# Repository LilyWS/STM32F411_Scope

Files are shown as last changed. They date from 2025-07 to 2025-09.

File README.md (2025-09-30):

Pretty much everything happens in main.c 

Signal conditioning phase consists of a voltage divider, diodes to clamp power to the rails, and an op-amp buffer to ensure proper current to the adc. 

I am interested in adding support for negative voltages through a dc bias to signals. I have yet to test the oscilliscopes capabilities thoroughly although it appears it's unable to accurately determine frequency past 150kHz or so.

The rightmost bread board is just a 555 for testing purposes. The middle one contains the signal condition phase and button inputs (which are still rather bouncy). 
The left most connects the STM32 to the screen, an ILI9488. 
The screen is rather slow to refresh, definetly not the best choice for this project. I regret powering the screen from the F411 as the power rails are rather inconsistent now (hence the need for reading Vrefint to infer true power voltage). I am interested in powering them separately in the future. 

The KiCad project folder for the PCB is the folder name Oscilliscope.







IOC
Clock

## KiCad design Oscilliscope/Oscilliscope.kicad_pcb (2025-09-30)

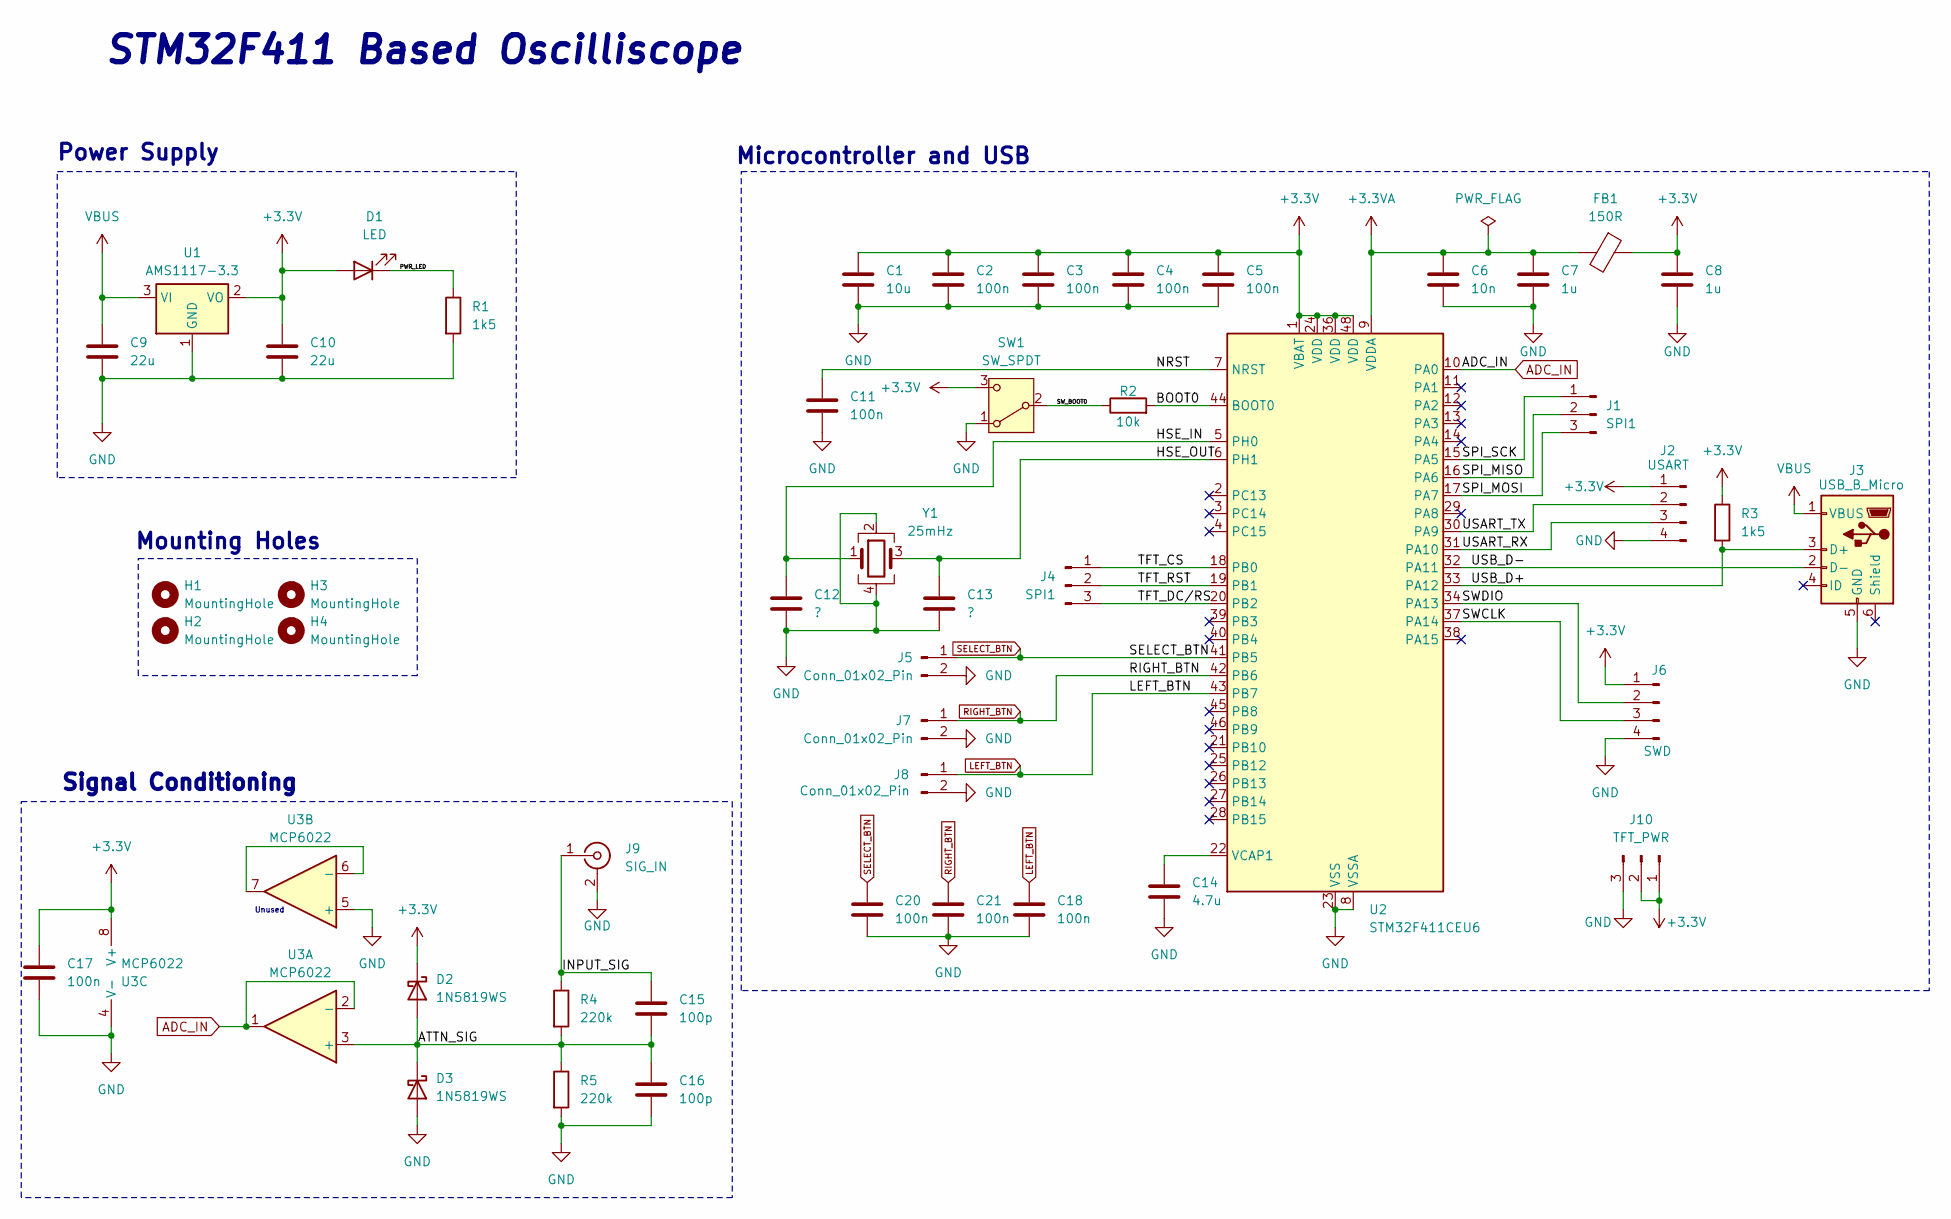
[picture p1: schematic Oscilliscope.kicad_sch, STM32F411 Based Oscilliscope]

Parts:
C1: 10u; C_0805_2012Metric
C2, C3, C4, C5, C11, C17, C18, C20, C21: 100n; C_0402_1005Metric
C6: 10n; C_0402_1005Metric
C7, C8: 1u; C_0402_1005Metric
C9, C10: 22u; C_0805_2012Metric
C12, C13: ?; C_0402_1005Metric
C14: 4.7u; C_0805_2012Metric
C15, C16: 100p; C_0402_1005Metric
D1: LED; LED_0603_1608Metric
D2, D3: 1N5819WS; D_SOD-323
FB1: 150R; L_0603_1608Metric
H1, H2, H3, H4: MountingHole; MountingHole_2.2mm_M2
J1, J4: SPI1; PinHeader_1x03_P2.54mm_Vertical
J2: USART; PinHeader_1x04_P2.54mm_Vertical
J3: USB_B_Micro; USB_Micro-B_Wuerth_629105150521
J5, J7, J8: Conn_01x02_Pin; PinHeader_1x02_P2.54mm_Vertical
J6: SWD; PinHeader_1x04_P2.54mm_Vertical
J9: SIG_IN; PinHeader_1x02_P2.54mm_Vertical
J10: TFT_PWR; PinHeader_1x03_P2.54mm_Vertical
R1, R3: 1k5; R_0402_1005Metric
R2: 10k; R_0402_1005Metric
R4, R5: 220k; R_0402_1005Metric
SW1: SW_SPDT; SW_SPDT_PCM12
U1: AMS1117-3.3; SOT-223-3_TabPin2
U2: STM32F411CEU6; QFN-48-1EP_7x7mm_P0.5mm_EP5.6x5.6mm
U3: MCP6022; DIP-8_W7.62mm
Y1: 25mHz; Crystal_SMD_3225-4Pin_3.2x2.5mm

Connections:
+3.3V: C1.1, C2.1, C3.1, C4.1, C5.1, C8.1, C10.1, C17.1, D1.2 (A), D2.1 (K), FB1.1, J2.1, J6.1, J10.1, J10.2, R3.1, SW1.3 (C), U1.2 (VO), U2.1 (VBAT), U2.24 (VDD), U2.36 (VDD), U2.48 (VDD), U3.8 (V+); also elsewhere on the board
+3.3VA: C6.1, C7.1, FB1.2, U2.9 (VDDA)
/ATTN_SIG: C15.2, C16.1, D2.2 (A), D3.1 (K), R4.2, R5.1, U3.3 (+)
/BOOT0: R2.2, U2.44 (BOOT0)
/HSE_IN: C12.1, U2.5 (PH0), Y1.1
/HSE_OUT: C13.1, U2.6 (PH1), Y1.3
/INPUT_SIG: C15.1, J9.1 (In), R4.1
/NRST: C11.1, U2.7 (NRST)
/PWR_LED: D1.1 (K), R1.1
/SPI_MISO: J1.2, U2.16 (PA6)
/SPI_MOSI: J1.3, U2.17 (PA7)
/SPI_SCK: J1.1, U2.15 (PA5)
/SWCLK: J6.3, U2.37 (PA14)
/SWDIO: J6.2, U2.34 (PA13)
/SW_BOOT0: R2.1, SW1.2 (B); also elsewhere on the board
/TFT_CS: J4.1, U2.18 (PB0)
/TFT_DC/RS: J4.3, U2.20 (PB2)
/TFT_RST: J4.2, U2.19 (PB1)
/USART_RX: J2.3, U2.31 (PA10)
/USART_TX: J2.2, U2.30 (PA9)
/USB_D+: J3.3 (D+), R3.2, U2.33 (PA12)
/USB_D-: J3.2 (D-), U2.32 (PA11)
ADC_IN: U2.10 (PA0), U3.1, U3.2 (-)
GND: C1.2, C2.2, C3.2, C4.2, C5.2, C6.2, C7.2, C8.2, C9.2, C10.2, C11.2, C12.2, C13.2, C14.2, C16.2, C17.2, C18.1, C20.1, C21.1, D3.2 (A), J2.4, J3.5 (GND), J5.2, J6.4, J7.2, J8.2, J9.2 (Ext), J10.3, R1.2, R5.2, SW1.1 (A), U1.1 (GND), U2.8 (VSSA), U2.23 (VSS), U2.35 (VSS), U2.47 (VSS), U2.49 (VSS), U3.4 (V-), U3.5 (+), Y1.2, Y1.4; also elsewhere on the board
LEFT_BTN: C18.2, J8.1, U2.43 (PB7)
unnamed: C14.1, U2.22 (VCAP1)
unnamed: U3.6 (-), U3.7
RIGHT_BTN: C21.2, J7.1, U2.42 (PB6)
SELECT_BTN: C20.2, J5.1, U2.41 (PB5)
VBUS: C9.1, J3.1 (VBUS), U1.3 (VI)

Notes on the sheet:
Mounting Holes
Microcontroller and USB
Power Supply
STM32F411 Based Oscilliscope
Unused
Signal Conditioning

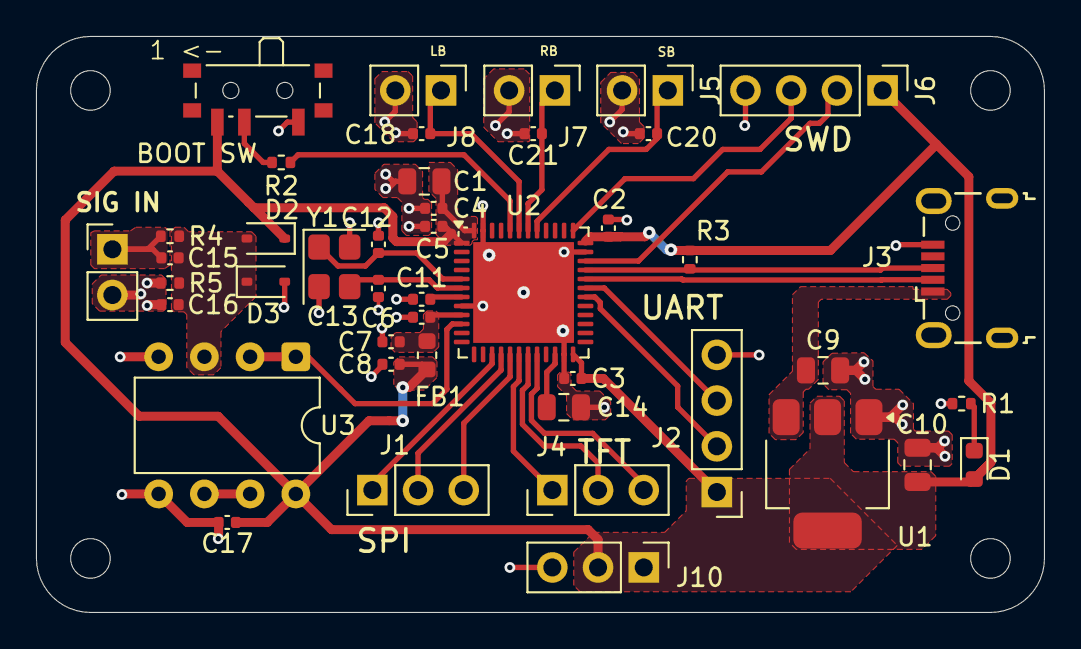
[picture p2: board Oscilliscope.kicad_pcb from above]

Board: 2 copper layers, 56.0 x 32.0 mm, 48 parts (0 on the bottom side), 30 nets.

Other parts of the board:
BOOT SW: SW_SPDT; SW_SPDT_PCM12

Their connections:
+3.3V: BOOT SW.3 (C); also elsewhere on the board
/SW_BOOT0: BOOT SW.2 (B); also elsewhere on the board
GND: BOOT SW.1 (A); also elsewhere on the board

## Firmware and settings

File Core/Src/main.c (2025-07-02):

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
/* Includes ------------------------------------------------------------------*/
#include "main.h"

/* USER CODE BEGIN Includes */
#include "ili9488.h"
#include "xpt2046.h"
#include "stdio.h"

#include "008_Open_Sans_Bold.h"
#include "009_Open_Sans_Bold.h"
#include "010_Open_Sans_Bold.h"
#include "012_Open_Sans_Bold.h"
#include "014_Open_Sans_Bold.h"
#include "016_Open_Sans_Bold.h"
#include "018_Open_Sans_Bold.h"
#include "020_Open_Sans_Bold.h"
#include "022_Open_Sans_Bold.h"
#include "024_Open_Sans_Bold.h"
#include "026_Open_Sans_Bold.h"
#include "028_Open_Sans_Bold.h"
#include "036_Open_Sans_Bold.h"
#include "048_Open_Sans_Bold.h"
#include "072_Open_Sans_Bold.h"
#include "096_Open_Sans_Bold.h"
#include "112_Open_Sans_Bold.h"
#include "128_Open_Sans_Bold.h"

#define _Open_Sans_Bold_8      &Open_Sans_Bold_8
#define _Open_Sans_Bold_9      &Open_Sans_Bold_9
#define _Open_Sans_Bold_10     &Open_Sans_Bold_10
#define _Open_Sans_Bold_11     &Open_Sans_Bold_11
#define _Open_Sans_Bold_12      &Open_Sans_Bold_12
#define _Open_Sans_Bold_14      &Open_Sans_Bold_14
#define _Open_Sans_Bold_16      &Open_Sans_Bold_16
#define _Open_Sans_Bold_18      &Open_Sans_Bold_18
#define _Open_Sans_Bold_20      &Open_Sans_Bold_20
#define _Open_Sans_Bold_22      &Open_Sans_Bold_22
#define _Open_Sans_Bold_24      &Open_Sans_Bold_24
#define _Open_Sans_Bold_26      &Open_Sans_Bold_26
#define _Open_Sans_Bold_28      &Open_Sans_Bold_28
#define _Open_Sans_Bold_36      &Open_Sans_Bold_36
#define _Open_Sans_Bold_48      &Open_Sans_Bold_48
#define _Open_Sans_Bold_72      &Open_Sans_Bold_72
#define _Open_Sans_Bold_96      &Open_Sans_Bold_96
#define _Open_Sans_Bold_112      &Open_Sans_Bold_112
#define _Open_Sans_Bold_128      &Open_Sans_Bold_128

volatile uint8_t SPI1_TX_completed_flag = 1;

char buf1[20];



#define RED2RED 0
#define GREEN2GREEN 1
#define BLUE2BLUE 2
#define BLUE2RED 3
#define GREEN2RED 4
#define RED2GREEN 5
#define BBLACK 6
//#define Aqua 7

#define BYELLOW 8


uint16_t AA[315]={315,314,313,312,311,310,309,308,307,306,305,304,303,302,301,300,299,298,297,296,
		295,294,293,292,291,290,289,288,287,286,285,284,283,282,281,280,279,278,277,276,275,274,
		273,272,271,270,269,268,267,266,265,264,263,262,261,260,259,258,257,256,255,254,253,252,
		251,250,249,248,247,246,245,244,243,242,241,240,239,238,237,236,235,234,233,232,231,230,
		229,228,227,226,225,224,223,222,221,220,219,218,217,216,215,214,213,212,211,210,209,208,
		207,206,205,204,203,202,201,200,199,198,197,196,195,194,193,192,191,190,189,188,187,186,
		185,184,183,182,181,180,179,178,177,176,175,174,173,172,171,170,169,168,167,166,165,164,
		163,162,161,160,159,158,157,156,155,154,153,152,151,150,149,148,147,146,145,144,143,142,
		141,140,139,138,137,136,135,134,133,132,131,130,129,128,127,126,125,124,123,122,121,120,
		119,118,117,116,115,114,113,112,111,110,109,108,107,106,105,104,103,102,101,100,99,98,97,
		96,95,94,93,92,91,90,89,88,87,86,85,84,83,82,81,80,79,78,77,76,75,74,73,72,71,70,69,68,67,
		66,65,64,63,62,61,60,59,58,57,56,55,54,53,52,51,50,49,48,47,46,45,44,43,42,41,40,39,38,37,
		36,35,34,33,32,31,30,29,28,27,26,25,24,23,22,21,20,19,18,17,16,15,14,13,12,11,10,9,8,7,6,5,
		4,3,2,1};

/* USER CODE END Includes */

/* USER CODE BEGIN PD */
//#define VREFINT_CAL_ADDR ((uint16_t*)0x1FFF7A2A) //compared against actual VREFINT to determine actual VDDA for ADC accuracy

/* USER CODE END PD */

ADC_HandleTypeDef hadc1;
DMA_HandleTypeDef hdma_adc1;

SPI_HandleTypeDef hspi1;
SPI_HandleTypeDef hspi2;
DMA_HandleTypeDef hdma_spi1_tx;

TIM_HandleTypeDef htim2;
TIM_HandleTypeDef htim3;

void SystemClock_Config(void);
static void MX_GPIO_Init(void);
static void MX_DMA_Init(void);
static void MX_ADC1_Init(void);
static void MX_SPI1_Init(void);
static void MX_SPI2_Init(void);
static void MX_TIM2_Init(void);
static void MX_TIM3_Init(void);
/* USER CODE BEGIN 0 */
void HAL_SPI_TxCpltCallback(SPI_HandleTypeDef *hspi)
{
	SPI1_TX_completed_flag = 1;
}


//ADC vars
#define ADC_BUF_LEN 1024//1024
#define SYSCLK_FREQ 100000000
#define CLOCKTIM_PRESC 0
volatile uint16_t adc_buf[ADC_BUF_LEN];
//test ADCVars
uint32_t adcValue = 0;
uint16_t adcCallbackTracker = 0; //track how many times buffer has filled so can call VREFINT
int triggerVDDAInfer = 0;
int triggerDisplay = 0;
char adcCharBuffer[16];

//stats to be kept track of for each buffer
uint16_t maxVoltage = 0;
uint16_t minVoltage = 4095;
uint32_t avgVoltage = 0;
double rmsVoltage = 0;
uint8_t attenuation = 2;
//triggering stuff
int triggering = 1; //if we should look for triggers
uint16_t triggerVoltage = 500; //voltage level needed to trigger
int triggersFound, triggerPoint1, triggerPoint2 = 0;
int risingTrigger = 0; //if trigger should be rising or falling
//timing stuff
uint32_t wavePeriod = 0;
uint32_t waveFrequency = 0;
uint32_t timerFrequency = 0;
uint32_t timeStep = 3; //timestep index : per div in microseconds
uint32_t timeStepOptions[11] = {35, 50, 100, 250, 500, 1000, 5000, 25000, 100000, 500000, 1000000};
//screen vars
uint8_t xDiv = 17;
uint8_t yDiv = 11;
uint8_t samplesPerDiv = 32; //should be a calculation ideally but okay to keep as constant . Found by (ADC_BUF_LEN/2)/(xDiv-1)
//manually selecting channels for VREFINT calibration, wont be needed later when switch to DMA
ADC_ChannelConfTypeDef ADC_CH_Cfg = {0};

//vars for VREFINT based ADC calibration
uint32_t vrefintReading = 0;
uint32_t inferredVDDA = 0;

//TESTING DELETE ME
uint16_t yTrack = 20;
uint16_t xTrack = 0;

//use reading from VREFINT to infer what real VDDA is
//assumes &hadc1
void inferVDDA(void){
	HAL_ADC_Stop_DMA(&hadc1);
	ADC1->CR2 &= ~(ADC_CR2_EXTEN | ADC_CR2_EXTSEL); // disable external trigger
	ADC_CH_Cfg.Channel = ADC_CHANNEL_VREFINT;        // Select The ADC Channel [i]
	ADC_CH_Cfg.Rank = 1;          // Must specify rank
	ADC_CH_Cfg.SamplingTime = ADC_SAMPLETIME_480CYCLES; // Use a long sample time
	HAL_ADC_ConfigChannel(&hadc1, &ADC_CH_Cfg); // Configure The Selected ADC Channel
    HAL_ADC_Start(&hadc1);                         // Start ADC Conversion @ Selected Channel
    HAL_ADC_PollForConversion(&hadc1, 1);         // Poll The ADC Channel With TimeOut = 1mSec

    vrefintReading = HAL_ADC_GetValue(&hadc1); // Read the result
    uint32_t vrefint_cal = *VREFINT_CAL_ADDR; // Factory calibration value
    //3300 is expected VDA in millivolts
    //dividing calibration value from factory by what was read to infer real VDDA
    inferredVDDA = (vrefint_cal*3300)/(vrefintReading);//(int)3.3f * (vrefint_cal / vrefintReading)*1000;

    HAL_ADC_Stop(&hadc1);
	ADC_CH_Cfg.Channel = ADC_CHANNEL_0;        // Select The ADC Channel
	ADC_CH_Cfg.Rank = 1;          // Must specify rank
	ADC_CH_Cfg.SamplingTime = ADC_SAMPLETIME_15CYCLES; //SET TO 15 RIGHT NOW FOR ACCURACY TAKE A LOOK AT LATER IF MORE SPEED IS NEEDED
	HAL_ADC_ConfigChannel(&hadc1, &ADC_CH_Cfg); // Configure The Selected ADC Channel
	ADC1->CR2 |= (ADC_CR2_EXTEN_0); // Rising edge
	ADC1->CR2 |= (ADC_CR2_EXTSEL_3); //Selects Timer 3 TRGO
}

//halffull ADC buffer callback
//void HAL_ADC_ConvHalfCpltCallback(ADC_HandleTypeDef* hadc) {
//	if (hadc->Instance == ADC1) {
//		// adc_buf[0] to adc_buf[half ADC_BUF_LEN-1] are ready to process
//		triggerDisplay = 1;
//		bufferHalf = 1;
//    }
//}
//full ADC Buffer Callback
void HAL_ADC_ConvCpltCallback(ADC_HandleTypeDef* hadc) {
	if (hadc->Instance == ADC1) {
		adcCallbackTracker += 1;
        // adc_buf[half ADC_BUF_LEN-1] to adc_buf[ADC_BUF_LEN-1] are ready to process
		triggerDisplay = 1;
		if(adcCallbackTracker>0){
			triggerVDDAInfer = 1;
			adcCallbackTracker = 0;
		}
    }
}
//display readings or whatever variable in a tiled update fashion
void testDMADisplay(){
	adcToVoltageString(adc_buf[2], adcCharBuffer, sizeof(adcCharBuffer), inferredVDDA);
//		sprintf(adcCharBuffer, "%lu", (unsigned long)inferredVDDA);
//		sprintf(adcCharBuffer, "%lu", (unsigned long)adcValue);

	LCD_Font(xTrack, yTrack, adcCharBuffer, _Open_Sans_Bold_24  , 1, WHITE);
	yTrack += 20;
	if(yTrack>300){
		xTrack += 100;
		yTrack = 20;
		if(xTrack > 400) {
			ILI9341_Fill_Screen(RED);
			yTrack = 0;
			xTrack = 0;
		}
	}
	HAL_Delay(250);
}

//adcVal = Reading from adc 0-4095
//voltageScale = Value in millivolts of what adc reading should scale to. Default 3.3V
// buffer and buffer size for snprintf
void adcToVoltageString(uint32_t adcVal, char* buffer, size_t bufferSize, uint32_t voltageScale){
    uint32_t millivolts = (adcVal * voltageScale) / 4095;

    // Extract whole volts and fractional part
    uint32_t volts = millivolts / 1000;
    uint32_t frac = millivolts % 1000;

    // Format as "X.XXX V"
    snprintf(buffer, bufferSize, "%lu.%03lu V", volts, frac);
}

void uiLoop(){

	drawGraticule(xDiv, yDiv, 20);
	if(triggering)
		findTrigger();
	graphData(340, 220, YELLOW);
	displayStats(20);
	//displayGraticuleStats(20);

//	adcToVoltageString(minVoltage, adcCharBuffer, sizeof(adcCharBuffer), inferredVDDA);
//	LCD_Font(200, 200, adcCharBuffer, _Open_Sans_Bold_24  , 1, WHITE);
//	adcToVoltageString(maxVoltage, adcCharBuffer, sizeof(adcCharBuffer), inferredVDDA);
//	LCD_Font(200, 100, adcCharBuffer, _Open_Sans_Bold_24  , 1, WHITE);
//
//	adcToVoltageString(avgVoltage, adcCharBuffer, sizeof(adcCharBuffer), inferredVDDA);
//	LCD_Font(200, 50, adcCharBuffer, _Open_Sans_Bold_24  , 1, WHITE);

	HAL_Delay(1);
}

//assumes graph top left corner at 0,0 and that x and y divs will be equal space. No option to change total width and length of graticule atm
void drawGraticule(uint16_t xDivCount, uint16_t yDivCount, uint16_t divLength) {
	uint16_t w = xDivCount * divLength;
	uint16_t h = yDivCount * divLength;

	setAddrWindow(0, 0, w-1, h-1);

	ILI9341_Draw_Colour_Burst(BLACK, w * h);
	for (int i = 0; i <= w; i += divLength)
		drawFastVLine(i, 0, h, WHITE);

    for (int i = 0; i <= h; i += divLength)
    	drawFastHLine(0, i, w, WHITE);

}

//w and h = width and height of graph area
void graphData(uint16_t w, uint16_t h, uint32_t color){
	w = w-2;
	maxVoltage = 0;
	minVoltage = 4095;
	avgVoltage = 0;
	rmsVoltage = 0;

	for(int i = 0; i<ADC_BUF_LEN/2; i++){
		int iPTP = i + triggerPoint1; //i plus trigger point
	    maxVoltage = (adc_buf[iPTP] > maxVoltage) ? adc_buf[iPTP] : maxVoltage;
	    minVoltage = (adc_buf[iPTP] < minVoltage) ? adc_buf[iPTP] : minVoltage;
	    avgVoltage += adc_buf[iPTP];
	    rmsVoltage += adc_buf[iPTP]*adc_buf[iPTP];
		if(i%4==0 && i>0){
	    	//LCD_Font((w*i)/ADC_BUF_LEN*2, h-((h)*adc_buf[iPTP])/4095, ".", _Open_Sans_Bold_20, 1, color);
			drawLine((w*(i-4))/ADC_BUF_LEN*2, h-((h)*adc_buf[iPTP-4])/4095, (w*i)/ADC_BUF_LEN*2, h-((h)*adc_buf[iPTP])/4095, color);
	    }
	}
	avgVoltage = avgVoltage/(ADC_BUF_LEN/2);
	rmsVoltage = sqrt(rmsVoltage/(ADC_BUF_LEN/2));
}

void findTrigger(){
	triggersFound = 0;
	triggerPoint1 = 0;
	triggerPoint2 = 0;
	waveFrequency = 0;
	wavePeriod = 0;
	for(int i = 0; i<ADC_BUF_LEN/2; i++){
        if ((risingTrigger && adc_buf[i] >= triggerVoltage && adc_buf[i - 1] < triggerVoltage) || (risingTrigger == 0 && adc_buf[i] <= triggerVoltage && adc_buf[i - 1] > triggerVoltage))
        {
            if (triggersFound==0) {
                triggerPoint1 = i;
                triggersFound = 1;
            }
            else // Looking for the second one
            {
            	if(triggerPoint2 == 0){
            		triggerPoint2 = i;
            		triggersFound = 2;

            	}
                break;

            }
        }
	}
	if(triggersFound==2){
		// get difference by samples of trigger points, mult by microseconds per 32 samples (timeStep), divide by 32
		wavePeriod = ((triggerPoint2-triggerPoint1)* timeStepOptions[timeStep])/samplesPerDiv;
		//period to frequency with 1 -> 1,000,000 so can divide by microseconds instead of seconds
		waveFrequency = 1000000/(wavePeriod);
	}

}

uint8_t rightButtonPressed = 0;
uint8_t leftButtonPressed = 0;
uint8_t selection = 0;
uint32_t last = 0;

//handle buttons
void HAL_GPIO_EXTI_Callback(uint16_t GPIO_Pin){
	uint32_t now = HAL_GetTick();
	if(now - last > 250){
		last = now;
	}else{
		return;
	}
	if(GPIO_Pin == SelectButton_Pin){
		selection = (selection > 2) ? 0 : selection+1;
		if(triggering==0 && (selection==1 || selection==2)){
			selection = 3;
		}
	}
	if(GPIO_Pin == LeftButton_Pin){
		leftButtonPressed = 1;
	}
	if(GPIO_Pin == RightButton_Pin){
			rightButtonPressed = 1;
	}
}

//stringBuffer for stat display
char stringBuffer[32];
void displayStats(uint8_t spacing){
	setAddrWindow(341, 0, ILI9488_TFTHEIGHT-1, ILI9488_TFTWIDTH-1);
	ILI9341_Draw_Colour_Burst(BLACK, 140*250);

	uint8_t pointer = 15;

	uint16_t postProcessedInferredVDDA = inferredVDDA * attenuation;

	adcToVoltageString(avgVoltage, adcCharBuffer, sizeof(adcCharBuffer), postProcessedInferredVDDA);
	snprintf(stringBuffer, sizeof(stringBuffer), "Vave: %s", adcCharBuffer);
	LCD_Font(350, pointer, stringBuffer, _Open_Sans_Bold_16  , 1, WHITE);
	pointer+=spacing;

	adcToVoltageString(rmsVoltage, adcCharBuffer, sizeof(adcCharBuffer), postProcessedInferredVDDA);
	snprintf(stringBuffer, sizeof(stringBuffer), "Vrms: %s", adcCharBuffer);
	LCD_Font(350, pointer, stringBuffer, _Open_Sans_Bold_16  , 1, WHITE);
	pointer+=spacing;

	adcToVoltageString(maxVoltage-minVoltage, adcCharBuffer, sizeof(adcCharBuffer), postProcessedInferredVDDA);
	snprintf(stringBuffer, sizeof(stringBuffer), "Vpp:   %s", adcCharBuffer);
	LCD_Font(350, pointer, stringBuffer, _Open_Sans_Bold_16  , 1, WHITE);
	pointer+=spacing;

	adcToVoltageString(maxVoltage, adcCharBuffer, sizeof(adcCharBuffer), postProcessedInferredVDDA);
	snprintf(stringBuffer, sizeof(stringBuffer), "Vmax:%s", adcCharBuffer);
	LCD_Font(350, pointer, stringBuffer, _Open_Sans_Bold_16  , 1, WHITE);
	pointer+=spacing;

	adcToVoltageString(minVoltage, adcCharBuffer, sizeof(adcCharBuffer), postProcessedInferredVDDA);
	snprintf(stringBuffer, sizeof(stringBuffer), "Vmin: %s", adcCharBuffer);
	LCD_Font(350, pointer, stringBuffer, _Open_Sans_Bold_16  , 1, WHITE);
	pointer+=spacing;

	snprintf(stringBuffer, sizeof(stringBuffer), "Triggering", adcCharBuffer);
	LCD_Font(350, pointer, stringBuffer, _Open_Sans_Bold_16, 1, (selection==0) ? YELLOW : (triggering) ? GREEN : RED);
	pointer+=spacing;

	if(triggering){

		snprintf(stringBuffer, sizeof(stringBuffer), (risingTrigger) ? "Rising Edge": "Falling Edge", adcCharBuffer);
		LCD_Font(350, pointer, stringBuffer, _Open_Sans_Bold_16, 1, (selection==1) ? YELLOW : WHITE);
		pointer+=spacing;

		adcToVoltageString(triggerVoltage, adcCharBuffer, sizeof(adcCharBuffer), postProcessedInferredVDDA);
		snprintf(stringBuffer, sizeof(stringBuffer), "TV: %s", adcCharBuffer);
		LCD_Font(350, pointer, stringBuffer, _Open_Sans_Bold_16  , 1, (selection==2) ? YELLOW : WHITE);
		pointer+=spacing;

		periodToString(wavePeriod, adcCharBuffer, sizeof(adcCharBuffer));
		snprintf(stringBuffer, sizeof(stringBuffer), "Cyc: %s", adcCharBuffer);
		LCD_Font(350, pointer, stringBuffer, _Open_Sans_Bold_16  , 1, WHITE);
		pointer+=spacing;

		frequencyToString(waveFrequency, adcCharBuffer, sizeof(adcCharBuffer));
		snprintf(stringBuffer, sizeof(stringBuffer), "F: %s", adcCharBuffer);
		LCD_Font(350, pointer, stringBuffer, _Open_Sans_Bold_16, 1, WHITE);
		pointer+=spacing;
	}


	periodToString(timeStepOptions[timeStep], adcCharBuffer, sizeof(adcCharBuffer));
	snprintf(stringBuffer, sizeof(stringBuffer), "xDiv: %s", adcCharBuffer);
	LCD_Font(350, pointer, stringBuffer, _Open_Sans_Bold_16  , 1, (selection==3) ? YELLOW : WHITE);
	pointer+=spacing;

	adcToVoltageString(410, adcCharBuffer, sizeof(adcCharBuffer), postProcessedInferredVDDA);
	snprintf(stringBuffer, sizeof(stringBuffer), "yDiv: %s", adcCharBuffer);
	LCD_Font(350, pointer, stringBuffer, _Open_Sans_Bold_16  , 1, WHITE);
}

void displayGraticuleStats(uint8_t spacing){
	setAddrWindow(0, 221, ILI9488_TFTHEIGHT-1, ILI9488_TFTWIDTH-1);
	ILI9341_Draw_Colour_Burst(WHITE, 140*200);
}

void periodToString(uint32_t period, char* buffer, size_t bufferSize){
    uint16_t milliSeconds = period / 1000;
    uint16_t microSeconds = period % 1000;

    snprintf(buffer, bufferSize, "%lu.%03lu ms", milliSeconds, microSeconds);
}

void frequencyToString(uint32_t freqVal, char* buffer, size_t bufferSize){
    uint16_t khz = freqVal / 1000;
    uint16_t hz = freqVal % 1000;
	snprintf(buffer, bufferSize, "%lu.%03lu kHz", khz, hz);
}


void fillBuffer() {
	triggerDisplay = 0;
//	htim3.Instance->CR1
	HAL_TIM_Base_Start(&htim3);
	HAL_ADC_Start_DMA(&hadc1, (uint32_t*)adc_buf, ADC_BUF_LEN);
	while(triggerDisplay==0);
	triggerDisplay=1;
	HAL_TIM_Base_Stop(&htim3);
}

void setTimerFreq(int freq){

	uint16_t arr = (SYSCLK_FREQ / ((CLOCKTIM_PRESC + 1) * freq)) - 1;
	htim3.Instance->ARR = arr;
	htim3.Instance->PSC = 0;//1279;
	//Update generation, reinits counter. Reference manual page 402
	htim3.Instance->EGR = TIM_EGR_UG;
}



int changeTimeStep = 0;

void processInput(){
	if(selection==0){
		if(rightButtonPressed || leftButtonPressed){
			triggering = (triggering==1) ? 0 : 1;
		}
	}else if(selection==1){
		if(rightButtonPressed || leftButtonPressed){
			risingTrigger = (risingTrigger==1) ? 0 : 1;
		}
	}else if(selection==2){
		if(rightButtonPressed){
			triggerVoltage = (triggerVoltage < 3997) ? triggerVoltage+100 : 0;
		}else if(leftButtonPressed){
			triggerVoltage = (triggerVoltage > 99) ? triggerVoltage-100 : 4000;
		}
	}else if (selection==3){
		if(rightButtonPressed){
			if (timeStep == 10){
				timeStep = 0;
			}else{
				timeStep += 1;
			}
			changeTimeStep = 1;
		}else if(leftButtonPressed){
			if (timeStep == 0){
				timeStep = 10;
			}else{
				timeStep += -1;
			}
			changeTimeStep = 1;
		}
	}
}

/* USER CODE END 0 */

/**
  * @brief  The application entry point.
  * @retval int
  */
int main(void)
{

  /* MCU Configuration--------------------------------------------------------*/

  /* Reset of all peripherals, Initializes the Flash interface and the Systick. */
  HAL_Init();

  /* Configure the system clock */
  SystemClock_Config();

  /* Initialize all configured peripherals */
  MX_GPIO_Init();
  MX_DMA_Init();
  MX_ADC1_Init();
  MX_SPI1_Init();
  MX_SPI2_Init();
  MX_TIM2_Init();
  MX_TIM3_Init();
  /* USER CODE BEGIN 2 */
  ILI9488_Init();

 //   HAL_Delay(1000);
    setRotation(1);


    //HAL_ADC_Start(&hadc1);
 //   uint16_t touchx = 0, touchy = 0;

    inferVDDA();
	ILI9341_Fill_Screen(BLACK);
//	drawImage(image_data_test, 0, 0, 480,80);
	//multiply samplesPerDiv by 1,000,000 in order to account for the fact that we measure timesteps in milliseconds. this avoids any pesky decimals
	timerFrequency = (samplesPerDiv*1000000)/timeStepOptions[timeStep];
	setTimerFreq(timerFrequency);
	invertDisplay(0);
	while (1) {
		fillBuffer();
		if(triggerVDDAInfer==1){
			//ILI9341_Fill_Screen(BLACK);
			triggerVDDAInfer = 0;
			inferVDDA();
		}
		if(leftButtonPressed || rightButtonPressed){
			processInput();
			rightButtonPressed = 0;
			leftButtonPressed = 0;
		}
		if(changeTimeStep == 1){
			timerFrequency = (samplesPerDiv*1000000)/timeStepOptions[timeStep];
			setTimerFreq(timerFrequency);
			changeTimeStep = 0;
		}
		uiLoop();
}



  /* USER CODE END 2 */

  /* Infinite loop */
}

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


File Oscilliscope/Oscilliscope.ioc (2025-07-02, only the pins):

Mcu.UserName=STM32F411CEUx
PA0-WKUP.Signal=ADCx_IN0
PA1.Signal=S_TIM2_CH2
PA2.Signal=S_TIM2_CH3
PA3.Signal=S_TIM2_CH4
PA6.Signal=SPI1_MISO
PA7.Signal=SPI1_MOSI
PA8.GPIO_Label=TP_IRQ
PA8.Signal=GPIO_Input
PB0.GPIO_Label=TFT_CS
PB0.Signal=GPIO_Output
PB1.GPIO_Label=TFT_RST
PB1.Signal=GPIO_Output
PB12.GPIO_Label=TP_CS
PB12.Signal=GPIO_Output
PB13.Signal=SPI2_SCK
PB14.Signal=SPI2_MISO
PB15.Signal=SPI2_MOSI
PB2.GPIO_Label=TFT_DC
PB2.Signal=GPIO_Output
PB3.Signal=SPI1_SCK
PB5.GPIO_Label=SelectButton
PB5.Signal=GPXTI5
PB6.GPIO_Label=RightButton
PB6.Signal=GPXTI6
PB7.GPIO_Label=LeftButton
PB7.Signal=GPXTI7
PC13-ANTI_TAMP.Signal=GPIO_Output

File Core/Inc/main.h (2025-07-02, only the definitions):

#define TFT_CS_Pin GPIO_PIN_0
#define TFT_CS_GPIO_Port GPIOB
#define TFT_RST_Pin GPIO_PIN_1
#define TFT_RST_GPIO_Port GPIOB
#define TFT_DC_Pin GPIO_PIN_2
#define TFT_DC_GPIO_Port GPIOB
#define TP_CS_Pin GPIO_PIN_12
#define TP_CS_GPIO_Port GPIOB
#define TP_IRQ_Pin GPIO_PIN_8
#define TP_IRQ_GPIO_Port GPIOA
#define SelectButton_Pin GPIO_PIN_5
#define SelectButton_GPIO_Port GPIOB
#define SelectButton_EXTI_IRQn EXTI9_5_IRQn
#define RightButton_Pin GPIO_PIN_6
#define RightButton_GPIO_Port GPIOB
#define RightButton_EXTI_IRQn EXTI9_5_IRQn
#define LeftButton_Pin GPIO_PIN_7
#define LeftButton_GPIO_Port GPIOB
#define LeftButton_EXTI_IRQn EXTI9_5_IRQn

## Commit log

2025-07-03 Adding Drivers
2025-09-30 Added PCB Files
    [Oscilliscope.kicad_pcb, Oscilliscope.kicad_sch]
2025-09-30 PCB Update
    [Oscilliscope.kicad_pcb]

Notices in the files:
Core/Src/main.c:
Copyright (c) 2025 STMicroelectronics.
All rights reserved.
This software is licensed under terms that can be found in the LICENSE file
